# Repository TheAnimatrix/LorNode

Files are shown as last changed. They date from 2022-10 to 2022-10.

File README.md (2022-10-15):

# Low Cost LoRA + ESP32 Board
**This page is a work in progress!**

## Features:
- Based on RA-01 and ESP32 WROOM Modules
- Small form factor (73x43 mm)
- Double LDO Setup to decrease current usage
- Direct USB Programming w/ CH340C
- Battery charging + Protection
	- Allows the use of cheaper batteries
- Onboard RGB LED
- Low quiescent current (upto 10uA) or Lower!
- Easily available BOM
- Low Cost
	- Easy to manufacture (2 layer pcb)
	- Single side part assembly
	- Easy to assemble parts (no QFN or similar packages)

## TODO:
- Final PCB Check
- PCB Fabrication
- Searchable PDF Schematic
- clean up BOM
- Quiescent current graphs/tests

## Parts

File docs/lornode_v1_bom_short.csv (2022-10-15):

Comment | Designator | Footprint | LCSC | Qty
SY7088DGC | U1 | SamacSys_Parts:SON50P300X200X90-9N-D |  | 1
MT3410L | U2 | Package_TO_SOT_SMD:SOT-23-5 |  | 1
CH340C | U3 | Package_SO:SOIC-16_3.9x9.9mm_P1.27mm |  | 1
ESP-12E | U4 | RF_Module:ESP-12E |  | 1
Ai-Thinker-Ra-01 | U5 | RF_Module:Ai-Thinker-Ra-01-LoRa |  | 1
TP4056 | U6 | SamacSys_Parts:SOIC127P600X175-9N |  | 1
FS312F-G | U7 | SamacSys_Parts:SOT95P280X145-6N |  | 1

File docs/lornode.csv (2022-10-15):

Comment | Designator | Footprint | LCSC
22uF | C1,C2,C3,C5,C6,C7,C8,C9,C10,C12,C15,C17 | Capacitor_SMD:C_0805_2012Metric
100nF | C11,C13,C14,C16,C18 | Capacitor_SMD:C_0603_1608Metric
1uF | C4 | Capacitor_SMD:C_0603_1608Metric
STDBY | D1 | LED_SMD:LED_0805_2012Metric
CHRG | D2 | LED_SMD:LED_0805_2012Metric
3.3V_LED | D3 | LED_SMD:LED_0805_2012Metric
5V_LED | D4 | LED_SMD:LED_0805_2012Metric
MOS_EXT_DIODE | D5 | SamacSys_Parts:DIOM5025X231N
CHG_IN | D6 | SamacSys_Parts:DIOM5025X231N
GND_L1 | H1 | MountingHole:MountingHole_3.2mm_M3_Pad
GND_L2 | H2 | MountingHole:MountingHole_3.2mm_M3_Pad
GND_L3 | H3 | MountingHole:MountingHole_3.2mm_M3_Pad
RA_CS | J10 | Connector_PinHeader_2.54mm:PinHeader_1x02_P2.54mm_Vertical
Pinout_RA | J12 | Connector_PinHeader_2.54mm:PinHeader_2x08_P2.54mm_Vertical
PWR_GND | J2 | Connector_PinHeader_2.54mm:PinHeader_1x02_P2.54mm_Vertical
Pinout_ESP | J3 | Connector_PinHeader_2.54mm:PinHeader_2x13_P2.54mm_Vertical
BATT_IN | J4 | TerminalBlock_Phoenix:TerminalBlock_Phoenix_PT-1,5-2-3.5-H_1x02_P3.50mm_Horizontal
TYPE-C-31-M-12 | J5 | extra:HRO_TYPE-C-31-M-12
CHG_IN | J6 | TerminalBlock_Phoenix:TerminalBlock_Phoenix_PT-1,5-2-3.5-H_1x02_P3.50mm_Horizontal
Conn_01x02 | J7 | Connector_PinHeader_2.54mm:PinHeader_1x02_P2.54mm_Vertical
Pinout_SD | J8 | Connector_PinHeader_1.27mm:PinHeader_2x04_P1.27mm_Vertical
1.5uH | L1 | Inductor_SMD:L_TracoPower_TCK-047_5.2x5.8mm
4.7uH | L2 | Inductor_SMD:L_TracoPower_TCK-047_5.2x5.8mm
YJL2301G | Q1 | Package_TO_SOT_SMD:SOT-23
FS8205A | Q2 | SamacSys_Parts:SOP65P640X120-8N
YJL2102W | Q3,Q4,Q5 | Package_TO_SOT_SMD:SOT-323_SC-70
300k | R1 | Resistor_SMD:R_0603_1608Metric
8k | R10 | Resistor_SMD:R_0603_1608Metric
4.8k | R11 | Resistor_SMD:R_0603_1608Metric
2.4k | R12 | Resistor_SMD:R_0603_1608Metric
DNP | R13 | Resistor_SMD:R_0603_1608Metric
220 | R14 | Resistor_SMD:R_0603_1608Metric
330 | R15,R22 | Resistor_SMD:R_0603_1608Metric
315.8k | R17 | Resistor_SMD:R_0603_1608Metric
10k | R18,R31,R32 | Resistor_SMD:R_0603_1608Metric
5.1k | R19,R20 | Resistor_SMD:R_0603_1608Metric
68k | R2 | Resistor_SMD:R_0603_1608Metric
470 | R23,R24,R33 | Resistor_SMD:R_0603_1608Metric
100R | R25 | Resistor_SMD:R_0603_1608Metric
100k | R26,R27,R28,R30,R34 | Resistor_SMD:R_0603_1608Metric
220k | R29 | Resistor_SMD:R_0603_1608Metric
0 | R3,R4,R6 | Resistor_SMD:R_0603_1608Metric
1M | R5,R16 | Resistor_SMD:R_0603_1608Metric
1k | R7,R8,R21 | Resistor_SMD:R_0603_1608Metric
12k | R9 | Resistor_SMD:R_0603_1608Metric
CHG_CUR_SEL | SW1 | Connector_PinHeader_2.54mm:PinHeader_2x04_P2.54mm_Vertical
ESP_FLASH | SW2 | Button_Switch_SMD:SW_Push_1P1T_NO_6x6mm_H9.5mm
ESP_RST | SW3 | Button_Switch_SMD:SW_Push_1P1T_NO_6x6mm_H9.5mm
SY7088DGC | U1 | SamacSys_Parts:SON50P300X200X90-9N-D
MT3410L | U2 | Package_TO_SOT_SMD:SOT-23-5
CH340C | U3 | Package_SO:SOIC-16_3.9x9.9mm_P1.27mm
ESP-12E | U4 | RF_Module:ESP-12E
Ai-Thinker-Ra-01 | U5 | RF_Module:Ai-Thinker-Ra-01-LoRa
TP4056 | U6 | SamacSys_Parts:SOIC127P600X175-9N
FS312F-G | U7 | SamacSys_Parts:SOT95P280X145-6N

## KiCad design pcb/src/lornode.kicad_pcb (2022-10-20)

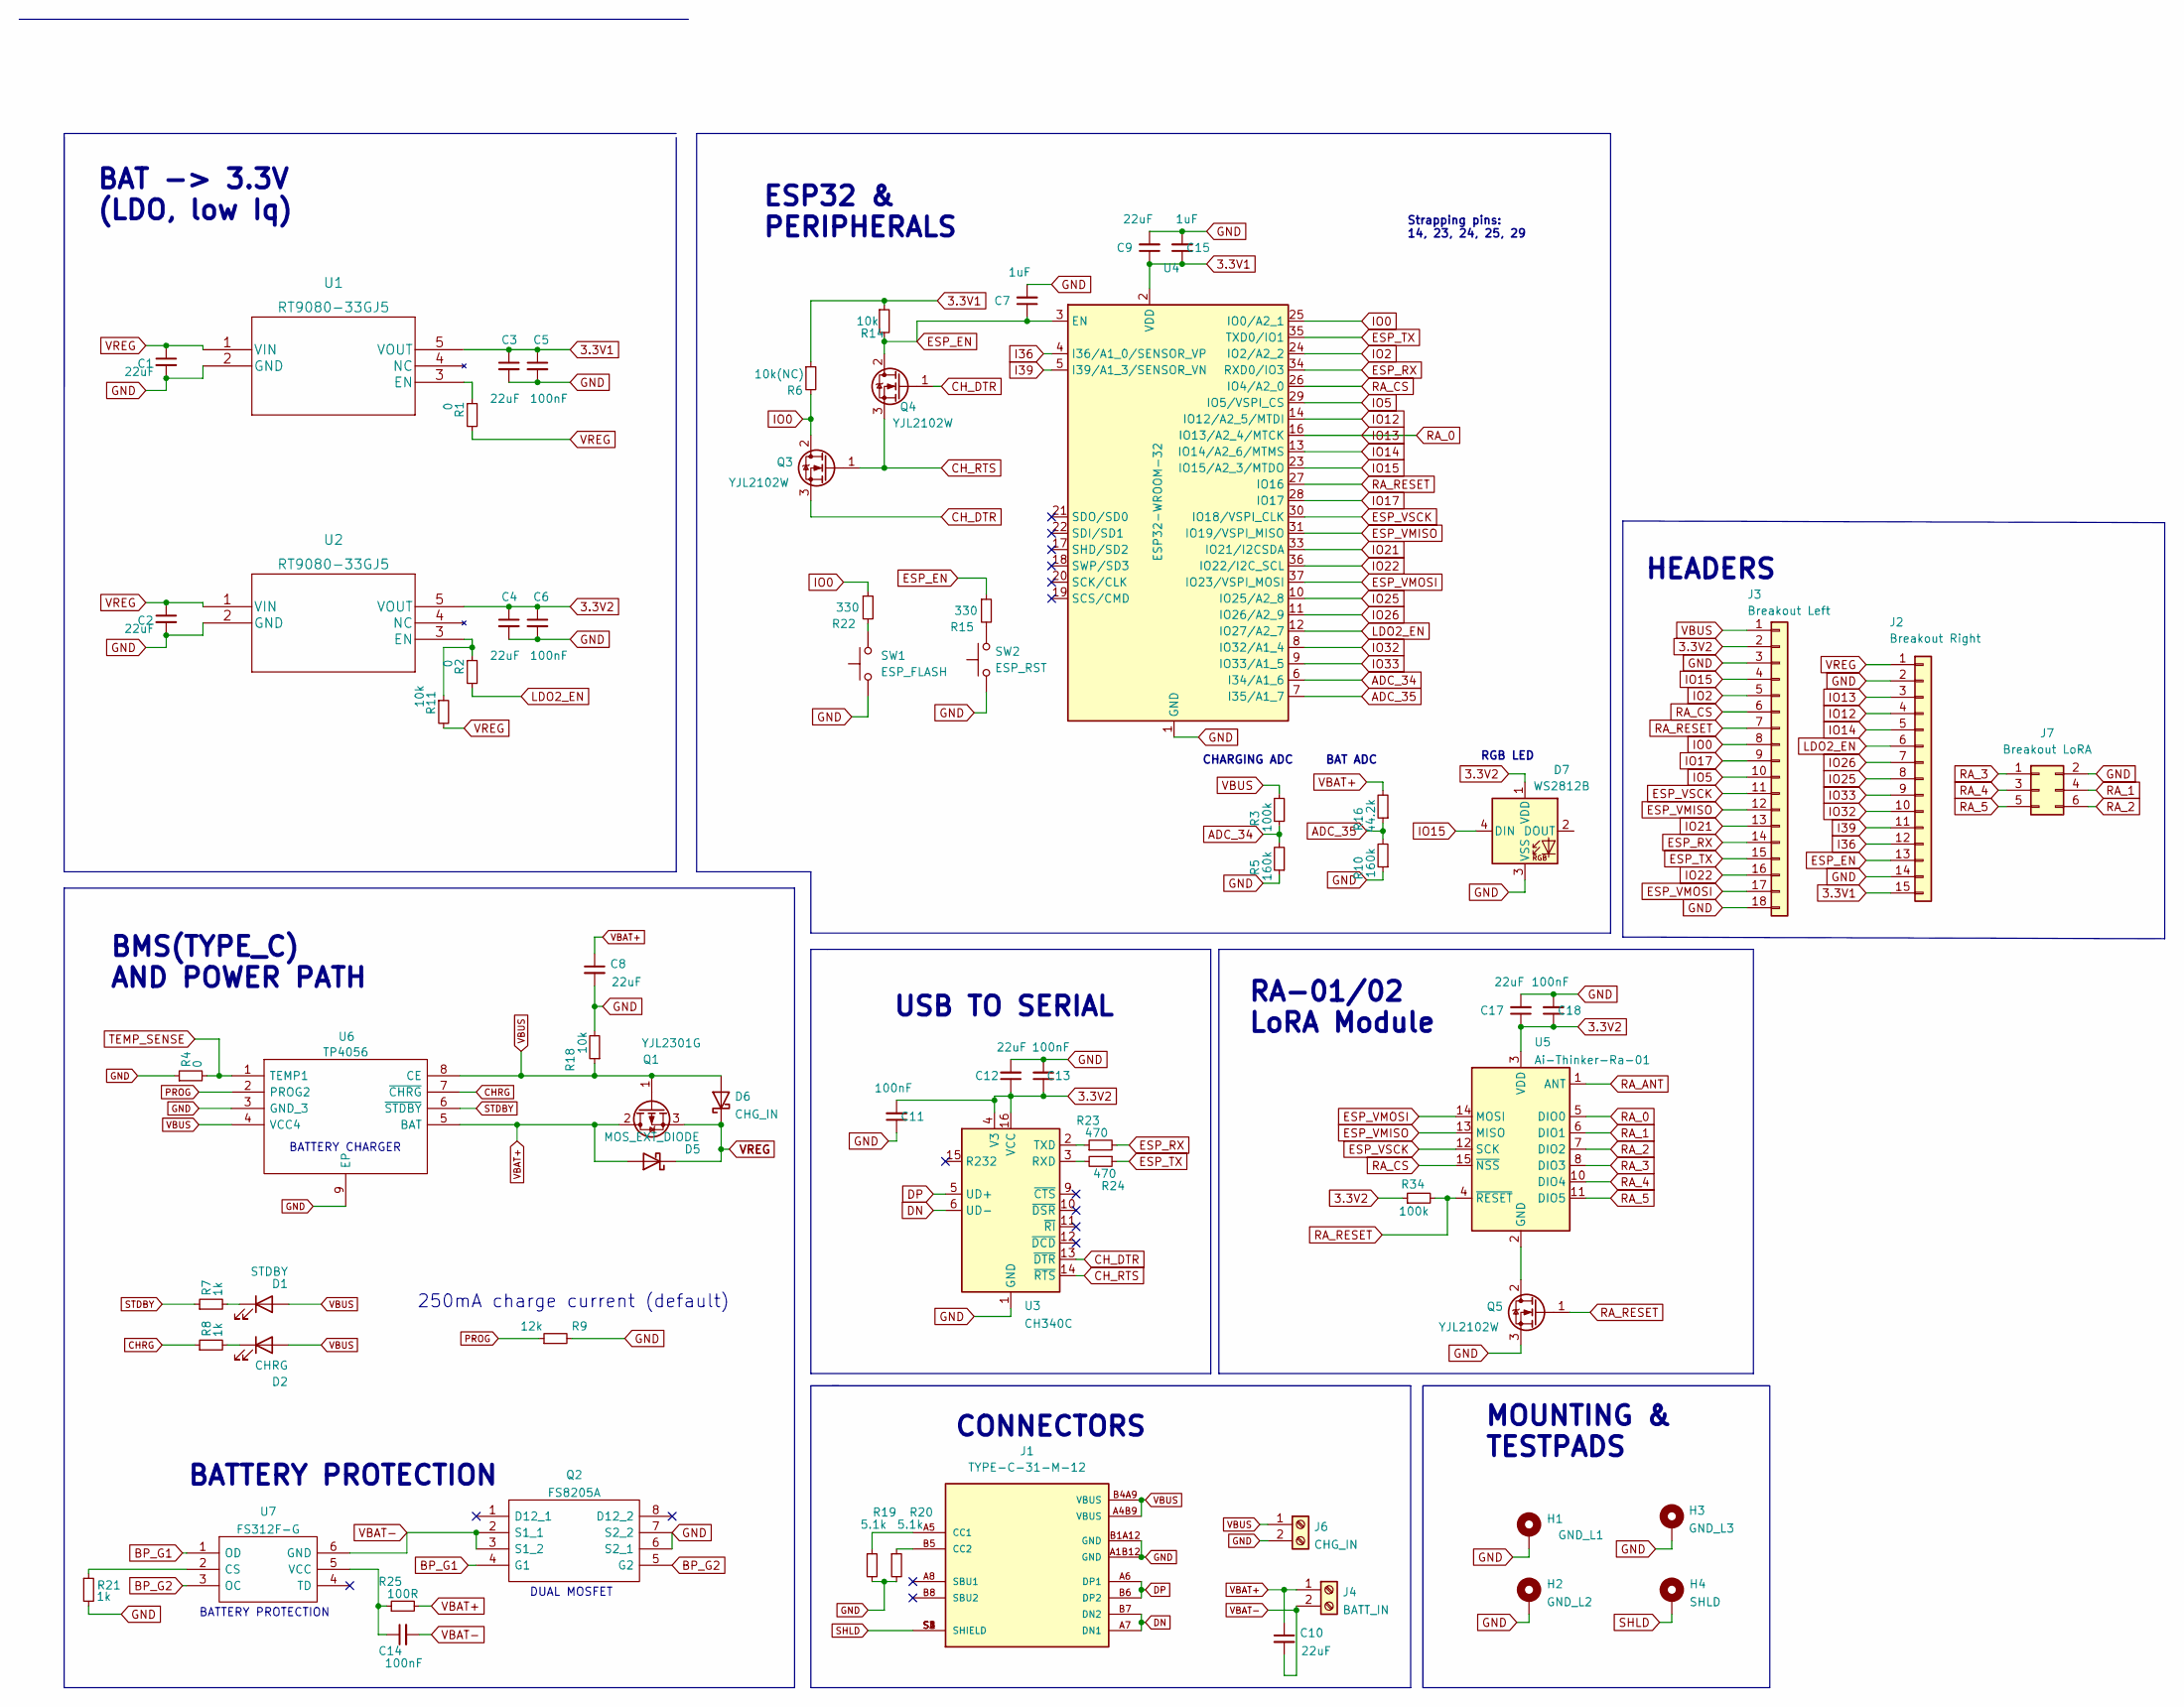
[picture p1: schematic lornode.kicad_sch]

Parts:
C1, C2, C3, C4, C8, C9, C10, C12, C17: 22uF; C_0805_2012Metric
C5, C6, C11, C13, C14, C18: 100nF; C_0603_1608Metric
C7, C15: 1uF; C_0603_1608Metric
D1: STDBY; LED_0805_2012Metric
D2: CHRG; LED_0805_2012Metric
D5: MOS_EXT_DIODE; DIOM5026X262N
D6: CHG_IN; DIOM5026X262N
D7: WS2812B; LED_WS2812B_PLCC4_5.0x5.0mm_P3.2mm
H1: GND_L1; MountingHole_3.2mm_M3_Pad
H2: GND_L2; MountingHole_3.2mm_M3_Pad
H3: GND_L3; MountingHole_3.2mm_M3_Pad
H4: SHLD; MountingHole_3.2mm_M3_Pad
J1: TYPE-C-31-M-12; B_TYPE-C-31-M-12; PARTREV 2020.12.08
J2: Breakout Right; PinHeader_1x15_P2.54mm_Vertical
J3: Breakout Left; PinHeader_1x18_P2.54mm_Vertical
J4: BATT_IN; TerminalBlock_Phoenix_PT-1,5-2-3.5-H_1x02_P3.50mm_Horizontal
J6: CHG_IN; TerminalBlock_Phoenix_PT-1,5-2-3.5-H_1x02_P3.50mm_Horizontal
J7: Breakout LoRA; PinHeader_2x03_P2.54mm_Vertical
Q1: YJL2301G; SOT-23
Q2: FS8205A; SOP65P640X120-8N; Manufacturer_Part_Number FS8205A
Q3, Q4, Q5: YJL2102W; SOT-323_SC-70
R1, R2, R4: 0; R_0603_1608Metric
R3, R34: 100k; R_0603_1608Metric
R5, R10: 160k; R_0603_1608Metric
R6: 10k(NC); R_0603_1608Metric
R7, R8, R21: 1k; R_0603_1608Metric
R9: 12k; R_0603_1608Metric
R11, R14, R18: 10k; R_0603_1608Metric
R15, R22: 330; R_0603_1608Metric
R16: 44.2k; R_0603_1608Metric
R19, R20: 5.1k; R_0603_1608Metric
R23, R24: 470; R_0603_1608Metric
R25: 100R; R_0603_1608Metric
SW1: ESP_FLASH; SKQYABE010
SW2: ESP_RST; SKQYABE010
U1, U2: RT9080-33GJ5
U3: CH340C; SOIC-16_3.9x9.9mm_P1.27mm
U4: ESP32-WROOM-32
U5: Ai-Thinker-Ra-01; Ai-Thinker-Ra-01-LoRa
U6: TP4056; SOIC127P600X175-9N; Manufacturer_Part_Number TP4056
U7: FS312F-G; SOT95P280X145-6N; Manufacturer_Part_Number FS312F-G

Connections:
3.3V1: C3.1, C5.1, C9.1, C15.1, J2.15, R6.1, R14.1, U1.5 (VOUT), U4.2 (VDD)
3.3V2: C4.1, C6.1, C11.2, C12.1, C13.1, C17.1, C18.1, D7.1 (VDD), J3.2, R34.1, U2.5 (VOUT), U3.4 (V3), U3.16 (VCC), U5.3 (VDD)
ADC_34: R3.1, R5.2, U4.6 (I34/A1_6)
ADC_35: R10.2, R16.1, U4.7 (I35/A1_7)
BP_G1: Q2.4 (G1), U7.1 (OD)
BP_G2: Q2.5 (G2), U7.3 (OC)
CHRG: R8.1, U6.7 (~CHRG)
CH_DTR: Q3.3 (S), Q4.1 (G), U3.13 (~DTR)
CH_RTS: Q3.1 (G), Q4.3 (S), U3.14 (~RTS)
DN: J1.A7 (DN1), J1.B7 (DN2), U3.6 (UD-)
DP: J1.A6 (DP1), J1.B6 (DP2), U3.5 (UD+)
ESP_EN: C7.1, J2.13, Q4.2 (D), R14.2, R15.1, U4.3 (EN)
ESP_RX: J3.14, R23.2, U4.34 (RXD0/IO3)
ESP_TX: J3.15, R24.1, U4.35 (TXD0/IO1)
ESP_VMISO: J3.12, U4.31 (IO19/VSPI_MISO), U5.13 (MISO)
ESP_VMOSI: J3.17, U4.37 (IO23/VSPI_MOSI), U5.14 (MOSI)
ESP_VSCK: J3.11, U4.30 (IO18/VSPI_CLK), U5.12 (SCK)
GND: C1.2, C2.2, C3.2, C4.2, C5.2, C6.2, C7.2, C8.2, C9.2, C11.1, C12.2, C13.2, C15.2, C17.2, C18.2, D7.3 (VSS), H1.1, H2.1, H3.1, J1.A1B12 (GND), J1.B1A12 (GND), J2.2, J2.14, J3.3, J3.18, J6.2, J7.2, Q2.6 (S2_1), Q2.7 (S2_2), Q5.3 (S), R4.1, R5.1, R9.2, R10.1, R18.2, R19.2, R20.2, R21.2, SW1.1, SW2.1, U1.2 (GND), U2.2 (GND), U3.1 (GND), U4.1 (GND), U4.15 (GND), U4.38 (GND), U4.39 (GND), U6.3 (GND_3), U6.9 (EP)
I36: J2.12, U4.4 (I36/A1_0/SENSOR_VP)
I39: J2.11, U4.5 (I39/A1_3/SENSOR_VN)
IO0: J3.8, Q3.2 (D), R6.2, R22.1, U4.25 (IO0/A2_1)
IO2: J3.5, U4.24 (IO2/A2_2)
IO5: J3.10, U4.29 (IO5/VSPI_CS)
IO12: J2.4, U4.14 (IO12/A2_5/MTDI)
IO13: J2.3, U4.16 (IO13/A2_4/MTCK), U5.5 (DIO0)
IO14: J2.5, U4.13 (IO14/A2_6/MTMS)
IO15: D7.4 (DIN), J3.4, U4.23 (IO15/A2_3/MTDO)
IO17: J3.9, U4.28 (IO17)
IO21: J3.13, U4.33 (IO21/I2CSDA)
IO22: J3.16, U4.36 (IO22/I2C_SCL)
IO25: J2.8, U4.10 (IO25/A2_8)
IO26: J2.7, U4.11 (IO26/A2_9)
IO32: J2.10, U4.8 (IO32/A1_4)
IO33: J2.9, U4.9 (IO33/A1_5)
LDO2_EN: J2.6, R2.2, U4.12 (IO27/A2_7)
unnamed: C14.1, R25.1, U7.5 (VCC)
unnamed: D1.1 (K), R7.2
unnamed: D2.1 (K), R8.2
unnamed: J1.A5 (CC1), R19.1
unnamed: J1.B5 (CC2), R20.1
unnamed: Q5.2 (D), U5.2 (GND), U5.9 (GND), U5.16 (GND)
unnamed: R1.1, U1.3 (EN)
unnamed: R2.1, R11.1, U2.3 (EN)
unnamed: R15.2, SW2.2
unnamed: R21.1, U7.2 (CS)
unnamed: R22.2, SW1.2
unnamed: R23.1, U3.2 (TXD)
unnamed: R24.2, U3.3 (RXD)
PROG: R9.1, U6.2 (PROG2)
RA_1: J7.4, U5.6 (DIO1)
RA_2: J7.6, U5.7 (DIO2)
RA_3: J7.1, U5.8 (DIO3)
RA_4: J7.3, U5.10 (DIO4)
RA_5: J7.5, U5.11 (DIO5)
RA_ANT: U5.1 (ANT)
RA_CS: J3.6, U4.26 (IO4/A2_0), U5.15 (~NSS)
RA_RESET: J3.7, Q5.1 (G), R34.2, U4.27 (IO16), U5.4 (~RESET)
SHLD: H4.1, J1.S1 (SHIELD), J1.S2 (SHIELD), J1.S3 (SHIELD), J1.S4 (SHIELD)
STDBY: R7.1, U6.6 (~STDBY)
TEMP_SENSE: R4.2, U6.1 (TEMP1)
VBAT+: C8.1, C10.1, D5.1 (A), J4.1, Q1.2 (D), R16.2, R25.2, U6.5 (BAT)
VBAT-: C10.2, C14.2, J4.2, Q2.2 (S1_1), Q2.3 (S1_2), U7.6 (GND)
VBUS: D1.2 (A), D2.2 (A), D6.2 (A), J1.A4B9 (VBUS), J1.B4A9 (VBUS), J3.1, J6.1, Q1.1 (G), R3.2, R18.1, U6.4 (VCC4), U6.8 (CE)
VREG: C1.1, C2.1, D5.2 (K), D6.1 (K), J2.1, Q1.3 (S), R1.2, R11.2, U1.1 (VIN), U2.1 (VIN)

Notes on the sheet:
MOUNTING & TESTPADS
BATTERY PROTECTION
RGB LED
CHARGING ADC
BAT ADC
ESP32 & PERIPHERALS
BATTERY CHARGER
RA-01/02 LoRA Module
CONNECTORS
Strapping pins: 14, 23, 24, 25, 29
BAT -> 3.3V (LDO, low Iq)
USB TO SERIAL
250mA charge current (default)
HEADERS
BMS(TYPE_C) AND POWER PATH
DUAL MOSFET

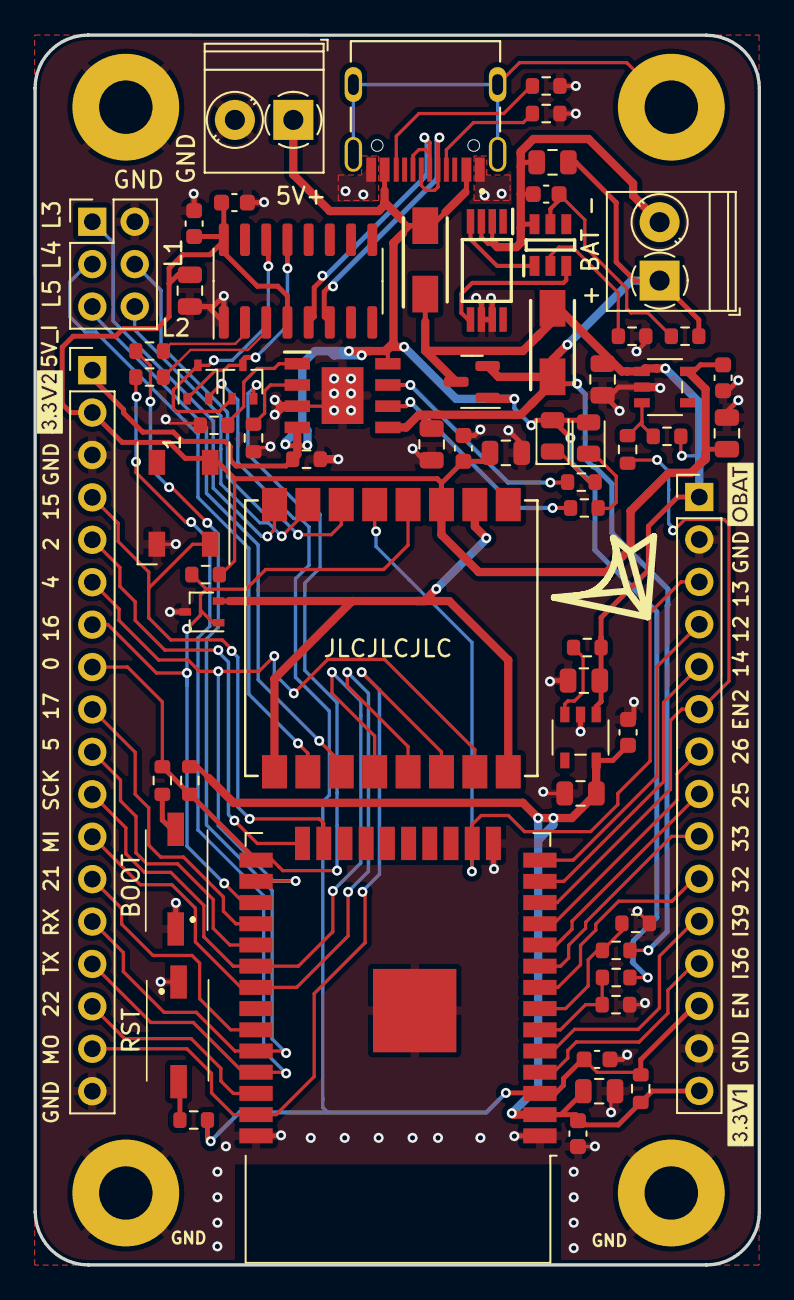
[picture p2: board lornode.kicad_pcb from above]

Board: 2 copper layers, 43.4 x 73.7 mm, 69 parts (0 on the bottom side), 63 nets.

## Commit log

2022-10-15 genesis. Lornode V2
    [esp_lora_iot-B_Cu.gbl, esp_lora_iot-B_Mask.gbs, esp_lora_iot-B_Paste.gbp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]
2022-10-20 v2 minor updates
    [lornode-B_Cu.gbl, lornode-B_Mask.gbs, lornode-B_Paste.gbp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]
